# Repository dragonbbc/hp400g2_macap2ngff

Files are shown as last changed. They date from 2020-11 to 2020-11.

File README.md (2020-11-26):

# HP ProDesk 400 G2 Desktop Mini PC专用的94360CS2转接卡
将网卡接口往SSD移动了一点，完美避开电容

网卡的座子找了好久也没找到到哪里可以买到（有知道的兄弟烦请告知），现在是从别的转接卡上拆了一个装过去的
# 安装效果图
avatar
# 食用方法
直接下载gerber拿去JLC打板就好，板厚选0.8，不做沉金工艺的话5元包邮即可，土豪请随意。

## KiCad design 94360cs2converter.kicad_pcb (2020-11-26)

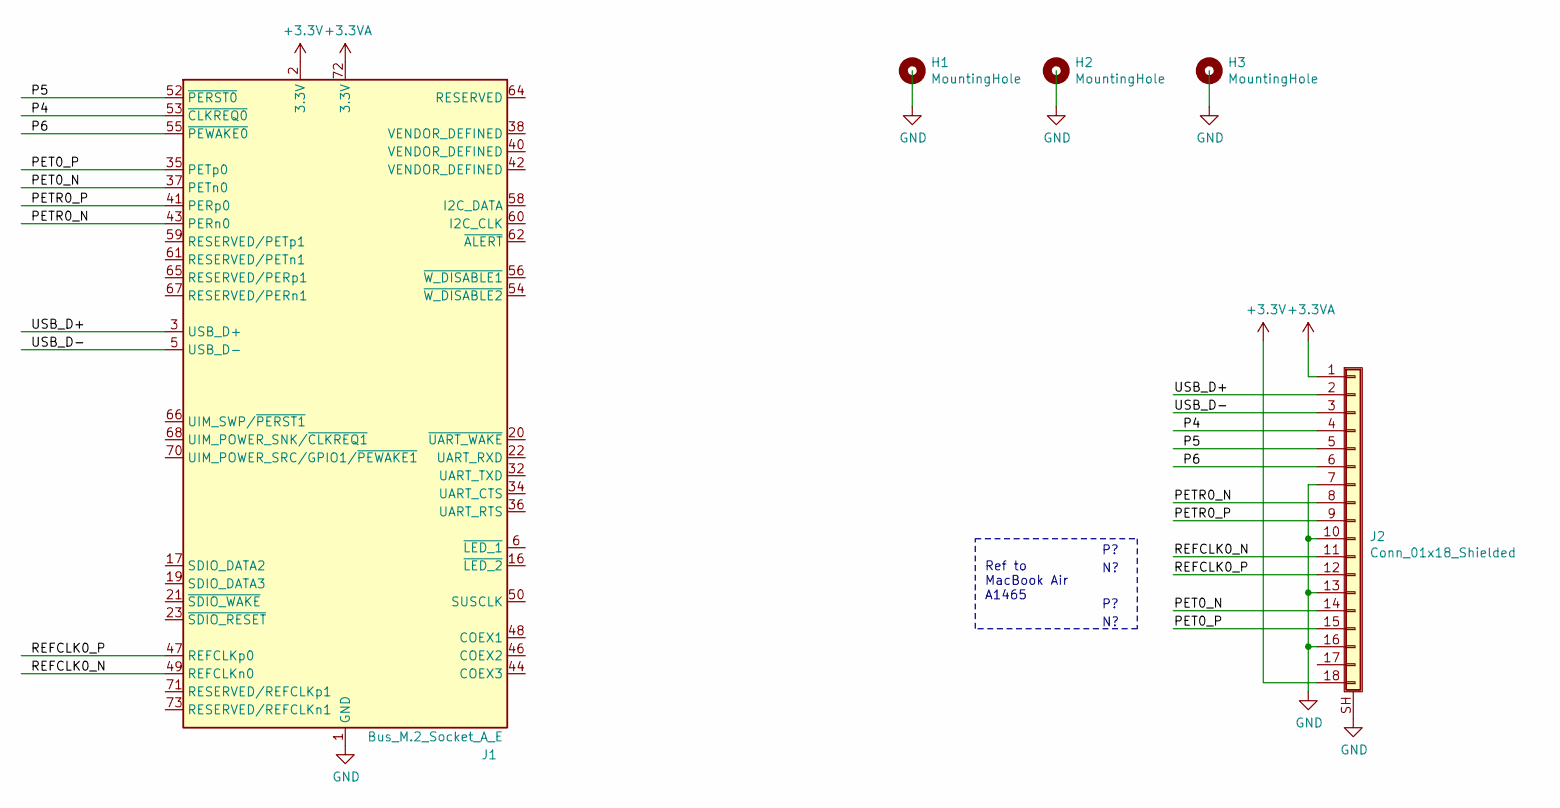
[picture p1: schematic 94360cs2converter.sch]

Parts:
H1: MountingHole; MountingHole_3mm_Pad_Via
H2, H3: MountingHole; MountingHole_3mm_Pad
J1: Bus_M.2_Socket_A_E; NGFF_A_E
J2: Conn_01x18_Shielded; MacWifiSocket

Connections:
+3.3VA: J1.72 (3.3V), J1.74 (3.3V), J2.1
+3V3: J1.2 (3.3V), J1.4 (3.3V), J2.18
/P4: J1.53 (~CLKREQ0), J2.4
/P5: J1.52 (~PERST0), J2.5
/P6: J1.55 (~PEWAKE0), J2.6
/PET0_N: J1.37 (PETn0), J2.14
/PET0_P: J1.35 (PETp0), J2.15
/PETR0_N: J1.43 (PERn0), J2.8
/PETR0_P: J1.41 (PERp0), J2.9
/REFCLK0_N: J1.49 (REFCLKn0), J2.11
/REFCLK0_P: J1.47 (REFCLKp0), J2.12
/USB_D+: J1.3 (USB_D+), J2.2
/USB_D-: J1.5 (USB_D-), J2.3
GND: H1.1, H2.1, H3.1, J1.1 (GND), J1.7 (GND), J1.18 (GND), J1.33 (GND), J1.39 (GND), J1.45 (GND), J1.51 (GND), J1.57 (GND), J1.63 (GND), J1.69 (GND), J1.75 (GND), J2.7, J2.10, J2.13, J2.16, J2.SH (Shield)

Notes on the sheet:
Ref to MacBook Air A1465

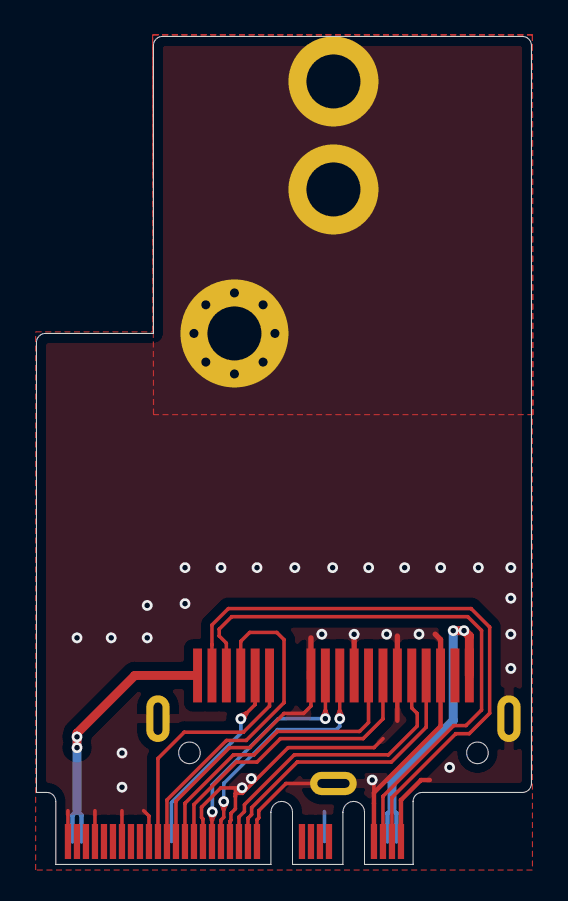
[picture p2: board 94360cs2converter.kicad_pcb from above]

Board: 2 copper layers, 27.5 x 46.0 mm, 5 parts (0 on the bottom side), 14 nets.

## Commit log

2020-11-26 增加安装效果图
2020-11-26 更换效果图为小一点的照片
